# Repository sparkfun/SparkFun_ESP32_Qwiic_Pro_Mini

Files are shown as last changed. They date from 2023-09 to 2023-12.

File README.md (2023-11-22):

SparkFun ESP32 Qwiic Pro Mini
========================================

SparkFun ESP32 Qwiic Pro Mini (https://www.sparkfun.com/products/23386)

[*SparkFun ESP32 Qwiic Pro Mini (23386)*](https://www.sparkfun.com/products/23386)

<Basic description of the part.>

Repository Contents
-------------------

* **/Hardware** - Eagle design files (.brd, .sch)
* **/Documents** - Files related to the ESP32 Qwiic Pro Mini
* **/Firmware** - Production panel files (.brd)

Documentation
--------------
* **[Hookup Guide](http://docs.sparkfun.com/SparkFun_ESP32_Qwiic_Pro_Mini)** - Basic hookup guide for the SparkFun ESP32 Qwiic Pro Mini.

License Information
-------------------

This product is _**open source**_! 

Please review the LICENSE.md file for license information. 

If you have any questions or concerns on licensing, please contact technical support on our [SparkFun forums](https://forum.sparkfun.com/viewforum.php?f=152).

Distributed as-is; no warranty is given.

- Your friends at SparkFun.

_<COLLABORATION CREDIT>_

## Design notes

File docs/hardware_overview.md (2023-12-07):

---
icon: material/cog
---

## ESP32 PICO Mini 

At the core of the SparkFun ESP32 Qwiic Pro Mini is the ESP32-PICO-MINI-02-N8R2 variant which includes 8MB Flash and 2MB PSRAM. There are two CPU cores that can be individually controlled, and the CPU clock frequency is adjustable from 80 MHz to 240 MHz. The chip also has a low-power coprocessor that can be used instead of the CPU to save power while performing tasks that do not require much computing power, such as monitoring of peripherals. For more information, refer to the [datasheet](assets/board_files/Espressif_Systems_04082021_ESP32_PICO_MINI_02_N8R2-2295871.pdf). 

<figure markdown>
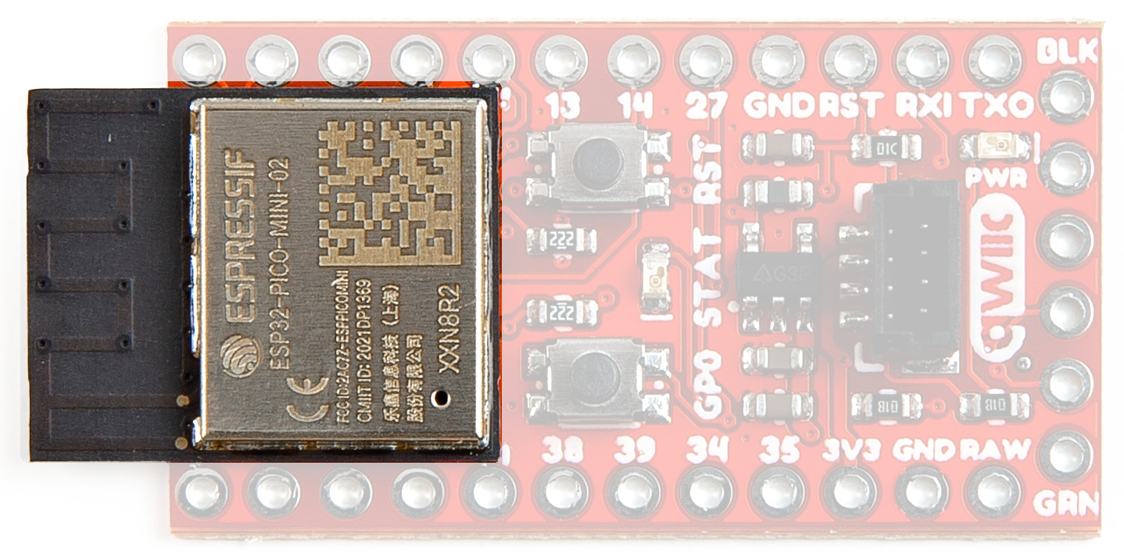
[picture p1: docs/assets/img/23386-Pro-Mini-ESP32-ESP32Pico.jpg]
ESP32 PICO Mini

<figcaption markdown>ESP32 PICO Mini</figcaption>
</figure>

## Power

Power is typically supplied via the VCC/GND pins using a [USB to Serial adapter](https://www.sparkfun.com/products/15096). Alternatively, external or portable power can be provided via the GND/RAW pins along the GPIO edge. Note: The AP2112K has a max input voltage of 6V.

The serial programming pins at the edge of the board are FTDI compatible and works best with our [CH340 USB to Serial breakout](https://www.sparkfun.com/products/15096). To utilize the GND/RAW pins along the GPIO edge, we recommend soldering the [JST Right-Angle Connector - Through-Hole 2-Pin](https://www.sparkfun.com/products/9749). 

<figure markdown>
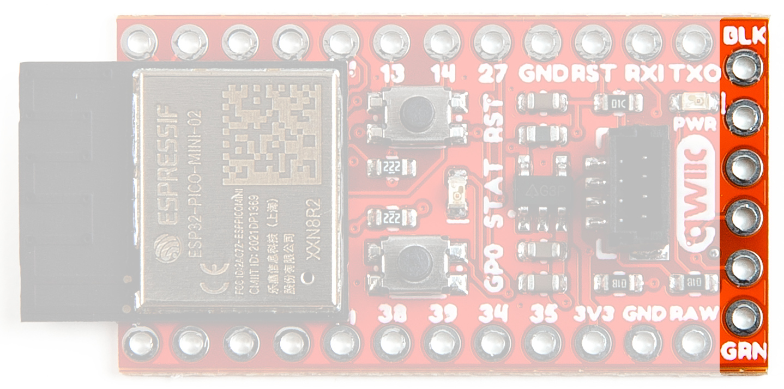
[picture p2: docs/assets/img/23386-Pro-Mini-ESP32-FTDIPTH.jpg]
FTDI PTHs

<figcaption markdown>Serial Programming Pins</figcaption>
</figure>

<figure markdown>
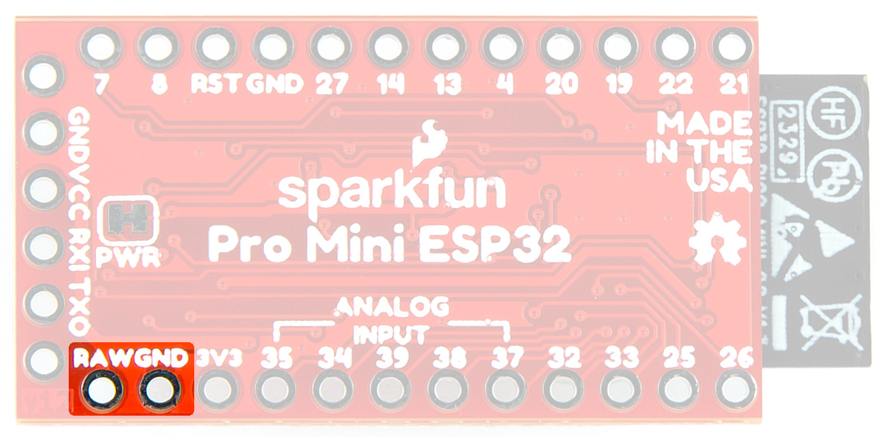
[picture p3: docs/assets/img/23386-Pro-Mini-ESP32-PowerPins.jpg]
Power PTHs

<figcaption markdown>Power Plated Through Holes</figcaption>
</figure>

## Voltage Regulator - AP2112K

The AP2112K Voltage Regulator ensures that the appropriate voltage is provided to the various components of the board. The AP2112K has a max input voltage of 6V.

<figure markdown>
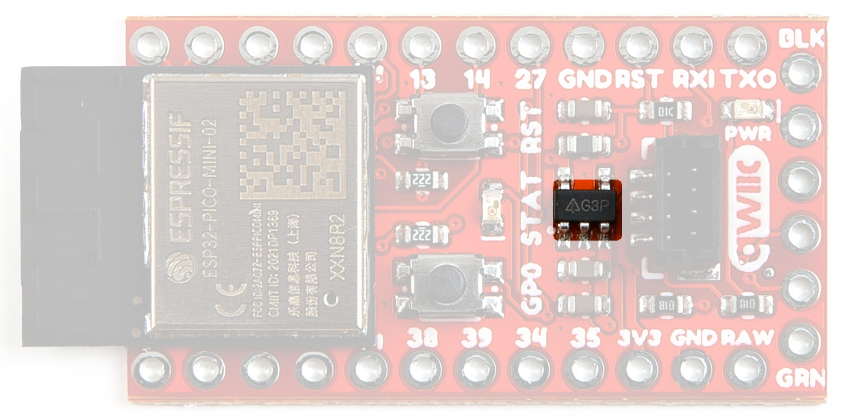
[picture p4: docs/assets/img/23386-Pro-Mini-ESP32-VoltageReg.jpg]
Voltage Regulator - AP2112K

<figcaption markdown>Voltage Regulator - AP2112K</figcaption>
</figure>

## Qwiic connector

The board includes a [Qwiic Connector](www.sparkfun.com/qwiic) for use with our vast array of Qwiic sensors. The I<sup>2</sup>C data and clock lines are tied to 2.2kΩ pull-up resistors.

Note that we've mounted the [Qwiic Connector](www.sparkfun.com/qwiic) vertically to prevent the occlusion of soldering and/or using the GPIO. 

<figure markdown>
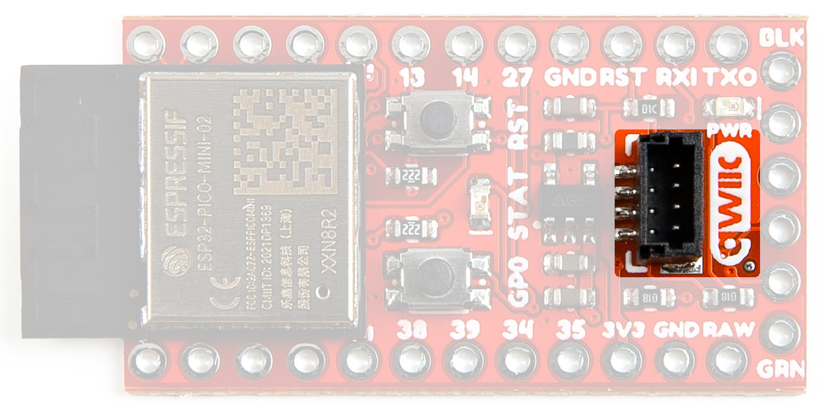
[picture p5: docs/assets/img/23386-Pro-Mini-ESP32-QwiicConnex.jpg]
Qwiic connector

<figcaption markdown>Qwiic connector</figcaption>
</figure>

## Buttons

There are two buttons on the board - Reset and Boot. The reset (RST) button allows users to reset the program running on the module without unplugging the board. The Boot Button allows the user to manually put the board into Bootloader Mode. To enter bootloader, hold the Boot button down when the ESP32 resets or powers on. These buttons are intentionally next to each other to make it a single finger rolling movement.

<figure markdown>
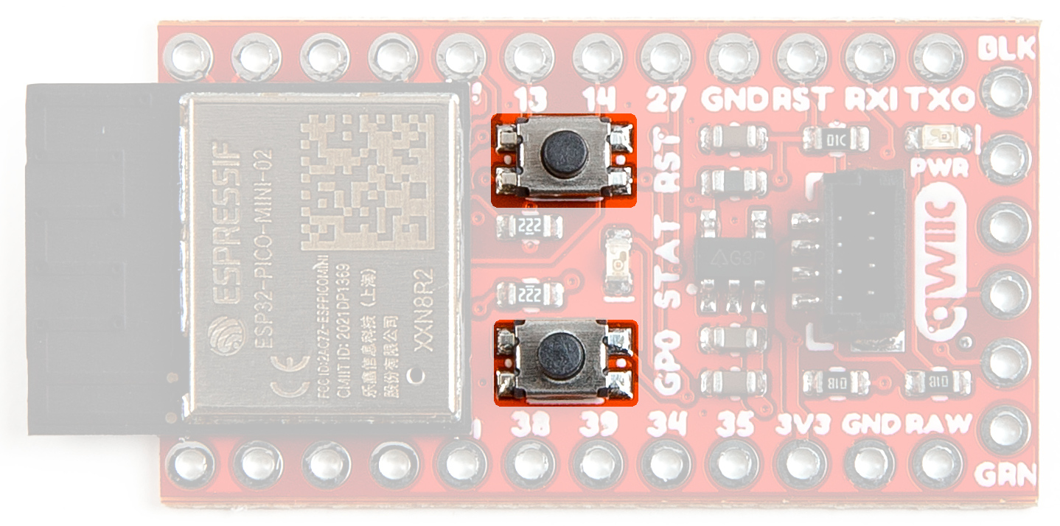
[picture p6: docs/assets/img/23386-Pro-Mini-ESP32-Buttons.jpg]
Buttons

<figcaption markdown>Buttons</figcaption>
</figure>

## LEDs

Two LEDs - Power(Red) and STAT(Blue) - show the user that power has been appropriately supplied to the board and the status of the data transfer. 

<figure markdown>
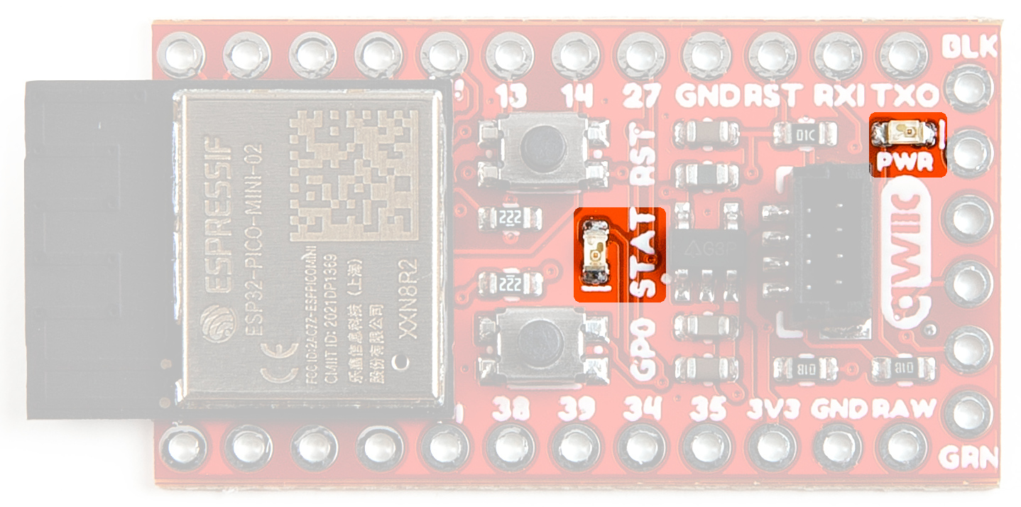
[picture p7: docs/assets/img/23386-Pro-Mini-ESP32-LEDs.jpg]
LEDs

<figcaption markdown>Power and Status LEDs</figcaption>
</figure>

## GPIO

The PTH pins are compatible with older Pro Minis. There are a few analog *input only* pins. They are labeled clearly.

<!--Use boot control pins with caution: 0, 2, 5, 12, 15
IO0: Avoid device connections. Can be used as a stat LED
IO2: Avoid external pullups - will cause bootloader fail
IO5: SDIO peripheral control. Has builtin pullup at POR
IO12: Avoid external pullups - will cause bootloader fail
IO15: Suppress output at POR. Has builtin pullup at POR
-->

<figure markdown>
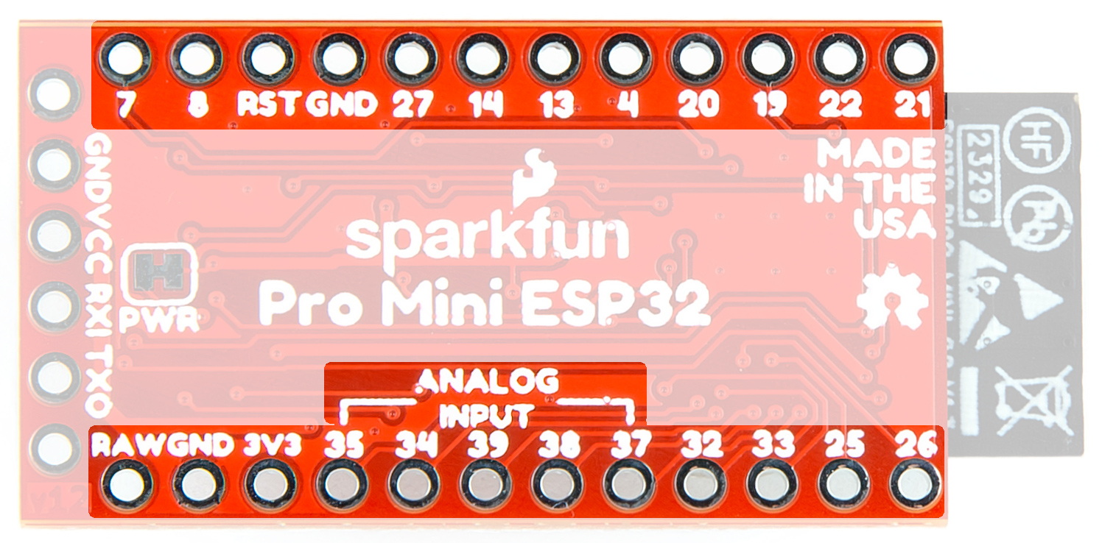
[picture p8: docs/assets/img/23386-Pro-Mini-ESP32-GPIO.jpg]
GPIO

<figcaption markdown>GPIO</figcaption>
</figure>

## Jumpers

??? note "Never modified a jumper before?"
	Check out our <a href="https://learn.sparkfun.com/tutorials/664">Jumper Pads and PCB Traces tutorial</a> for a quick introduction!
	<p align="center">
		<a href="https://learn.sparkfun.com/tutorials/664">
		Tutorial's thumbnail<br>
        How to Work with Jumper Pads and PCB Traces</a>
	</p>

### Power Jumper

If you have concerns about power consumption, need to run dark, or really just don't like LEDs, you can cut this jumper to disable the red PWR LED on the front of the board.

<figure markdown>
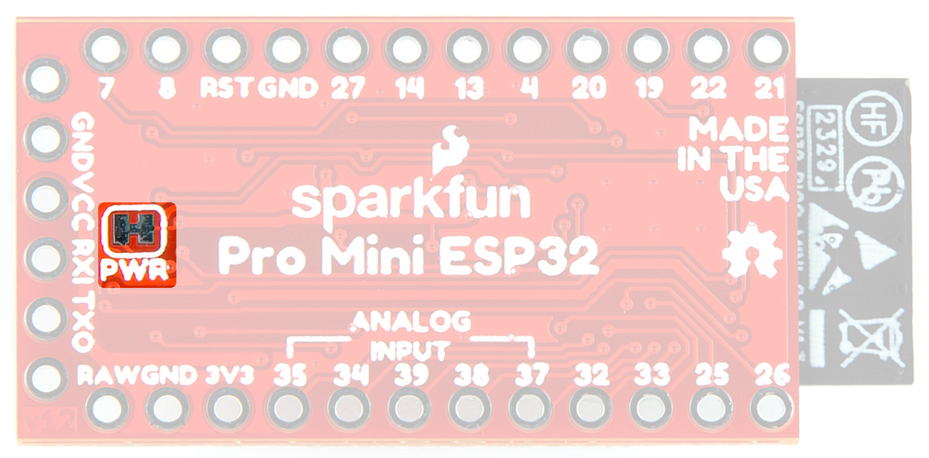
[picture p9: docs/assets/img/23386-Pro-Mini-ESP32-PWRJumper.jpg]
Power Jumper

<figcaption markdown>Power Jumper</figcaption>
</figure>

## Board Dimensions

The board dimensions are illustrated in the drawing below; the listed measurements are in inches.

<figure markdown>
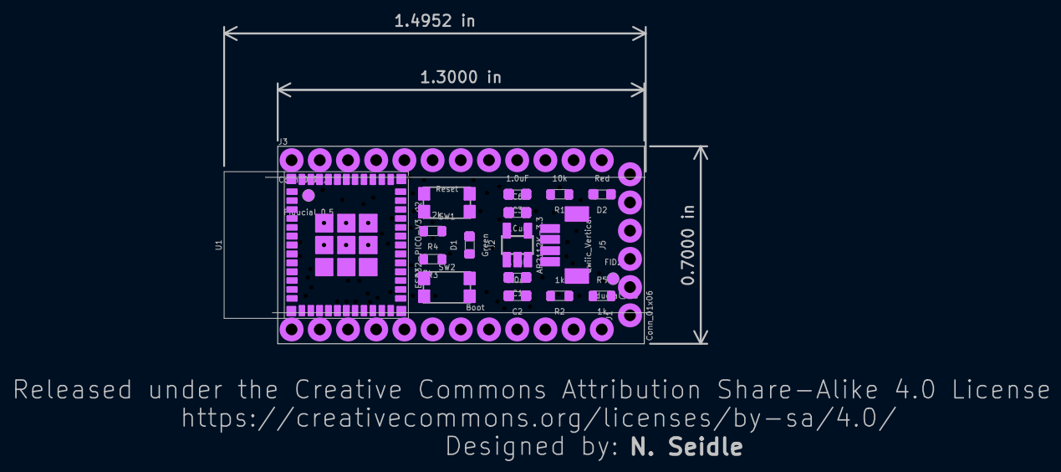
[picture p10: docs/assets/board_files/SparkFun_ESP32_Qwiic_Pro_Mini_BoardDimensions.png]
ESP32 Qwiic Pro Mini Board Dimensions

<figcaption markdown>ESP32 Qwiic Pro Mini Board Dimensions</figcaption>
</figure>

??? tip "Need more measurements?"
	For more information about the board's dimensions, users can download the [KiCad files](assets/board_files/SparkFun_ESP32_Qwiic_Pro_Mini-KiCadFiles.zip) for the board. These files can be opened in KiCad and additional measurements can be made with the dimensions tool.

	??? info ":octicons-download-16:{ .heart } KiCAD - Free Download!"
		KiCAD is a [CAD]("computer-aided design") program for electronics that is free to use for hobbyists and students. However, it does require an account registration to utilize the software.

		<center>
		[Download from<br>:autodesk-primary:{ .autodesk }](https://www.kicad.org/download/ "Go to downloads page"){ .md-button .md-button--primary width="250px" }
		</center>

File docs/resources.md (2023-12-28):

<!-- This section should include all the relevant documentation and product files (Eagle files, schematic, datasheet(s), landing pages, etc. and any relevant tutorials to go beyond the Hookup Guide.) -->

For more resources related to the SparkFun ESP32 Qwiic Pro Mini, check out the links listed here: 

* [Product Page](https://www.sparkfun.com/products/23386)
* [Schematic](assets/board_files/SparkFun_ESP32_Qwiic_Pro_Mini_SchematicV12.pdf) (PDF)
* [KiCAD Files](assets/board_files/SparkFun_ESP32_Qwiic_Pro_Mini-KiCAD_V12.zip) (ZIP)
* [Board Dimensions](assets/board_files/SparkFun_ESP32_Qwiic_Pro_Mini_BoardDimensions.png) (PDF)
* [Hardware GitHub Respository](https://github.com/sparkfun/SparkFun_ESP32_Qwiic_Pro_Mini)

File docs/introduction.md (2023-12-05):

---
icon: material/book-open-page-variant
---

<div class="grid cards desc" markdown>

-    <a href="https://www.sparkfun.com/products/23386">
    **SparkFun ESP32 Qwiic Pro Mini**<br>
    **SKU:** DEV-23386

    ---

    <figure markdown>
    Product Thumbnail
    </figure></a>
    
-    The SparkFun ESP32 Qwiic Pro Mini houses the powerful ESP32-PICO-MINI-02-N8R2 variant from Espressif on our mini footprint. With two individually controllable CPU cores, adjustable CPU clock frequency, 8MB Flash,  2MB PSRAM, a co-processor that can be used in situations that require minimal computing power, as well as a rich set of peripherals such as capabilities for SD card interface, capacitive touch sensors, ADC, DAC, Two-Wire Automotive Interface, to Ethernet, high-speed SPI, UART, I²S, and I²C. 

    <center>
    [Purchase from SparkFun :fontawesome-solid-cart-plus:{ .heart }](https://www.sparkfun.com/products/23386){ .md-button .md-button--primary }
    </center>

</div>

## Required Materials

To follow along with this tutorial, you will need the following materials. You may not need everything though depending on what you have. Add it to your cart, read through the guide, and adjust the cart as necessary.

<table style="border-style:none">
    <tr>
        <td>
            <a href="https://www.sparkfun.com/products/23386">
                <center>SparkFun ESP32 Qwiic Pro Mini</center>
                <h3 class="title">SparkFun ESP32 Qwiic Pro Mini</h3>
            </a>
            DEV-23386
        </td>
        <td>
            <a href=" https://www.sparkfun.com/products/15096">
                <center>SparkFun Serial Basic Breakout - CH340C and USB-C</center>
                <h3 class="title">SparkFun Serial Basic Breakout - CH340C and USB-C</h3>
            </a>
            DEV-15096
        </td>
        <td>
            <a href="https://www.sparkfun.com/products/15425">
                <center>Reversible USB A to C Cable - 0.8m
                </center>
                <h3 class="title">Reversible USB A to C Cable - 0.8m</h3>
            </a>
            CAB-15425
        </td>
    </tr>
</table>

## Suggested Reading

As a more professionally oriented product, we will skip over the more fundamental tutorials (i.e. [**Ohm's Law**](https://learn.sparkfun.com/tutorials/voltage-current-resistance-and-ohms-law) and [**What is Electricity?**](https://learn.sparkfun.com/tutorials/what-is-electricity)). However, below are a few tutorials that may help users familiarize themselves with various aspects of the board.

<div class="grid cards hide col-4" markdown align="center">

-   <a href="https://learn.sparkfun.com/tutorials/how-to-solder-through-hole-soldering">
    <figure markdown>
    How to Solder: Through-Hole Soldering
    </figure>
    </a>
    <a href="https://learn.sparkfun.com/tutorials/how-to-solder-through-hole-soldering">**How to Solder: Through-Hole Soldering**
    </a>

-   <a href="https://learn.sparkfun.com/tutorials/sparkfun-serial-basic-ch340c-hookup-guide">
    <figure markdown>
    SparkFun Serial Basic CH340C Hookup Guide
    </figure>
    </a>
    <a href="https://learn.sparkfun.com/tutorials/sparkfun-serial-basic-ch340c-hookup-guide">**SparkFun Serial Basic CH340C Hookup Guide**
    </a>    

-   <a href="https://learn.sparkfun.com/tutorials/82">
    <figure markdown>
    I2C
    </figure>
    </a>
    <a href="https://learn.sparkfun.com/tutorials/82">**I2C**
    </a>

-   <a href="https://learn.sparkfun.com/tutorials/analog-vs-digital">
    <figure markdown>
    Analog vs. Digital
    </figure>
    </a>
    <a href="https://learn.sparkfun.com/tutorials/analog-vs-digital">**Analog vs. Digital**
    </a>

-   <a href="https://learn.sparkfun.com/tutorials/serial-peripheral-interface-spi">
    <figure markdown>
    SPI
    </figure>
    </a>
    <a href="https://learn.sparkfun.com/tutorials/serial-peripheral-interface-spi">**SPI**
    </a>
</div>

<center>
<div align="center">
    <div style="top:5px;left:5px;background-color:Gray;position:relative">
        <div style="top:-5px;left:-5px;background-color:#ffffff;position:relative;border:1px solid black;">
            <a href="https://www.sparkfun.com/qwiic">Qwiic Connect System</a>
        </div>
    </div>
</div>
</center>

The SparkFun ESP32 Qwiic Pro Mini takes advantage of the [Qwiic connect system](https://www.sparkfun.com/qwiic). We recommend familiarizing yourself with the **Logic Levels** and **I<sup>2</sup>C** tutorials.  Click on the banner above to learn more about [Qwiic products](https://www.sparkfun.com/qwiic).

<center>
    <iframe width="600" height="327" src="https://www.youtube.com/embed/x0RDEHqFIF8" title="SparkFun's Qwiic Connect System" frameborder="0" allow="accelerometer; autoplay; clipboard-write; encrypted-media; gyroscope; picture-in-picture" allowfullscreen></iframe>
</center>

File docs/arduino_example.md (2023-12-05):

---
icon: simple/arduino
---

Now that we've installed the espressif boards package in Arduino, it's time to upload our first sketch to make sure everything is working properly.

### Example - Blink 

This basic example makes sure the board package installed correctly and the board accepts programming properly to blink the green STAT LED on the board every second. Open the example in Arduino by navigating to File > Examples > Basics > 01-Blink.

You will need to modify LED_BUILTIN to pin 0 like so: 

<figure markdown>
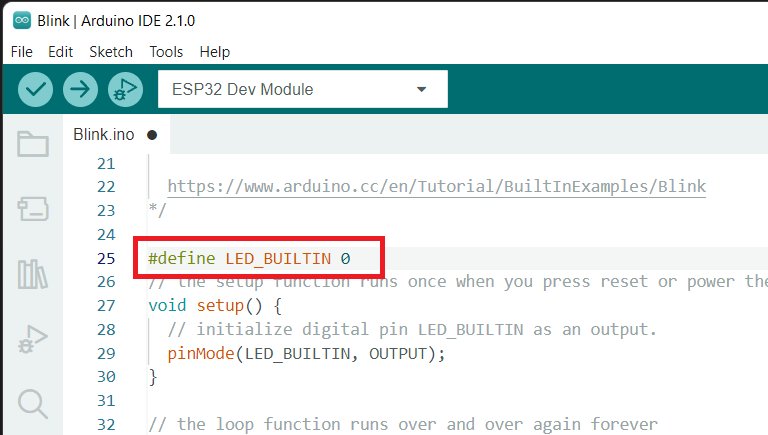
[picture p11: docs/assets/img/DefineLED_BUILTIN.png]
LED Builtin is Defined

<figcaption markdown>Code changes for LED_BUILTIN</figcaption>
</figure>

Make sure you have the board (ESP32 Dev Board) and select your applicable COM port: 

<figure markdown>
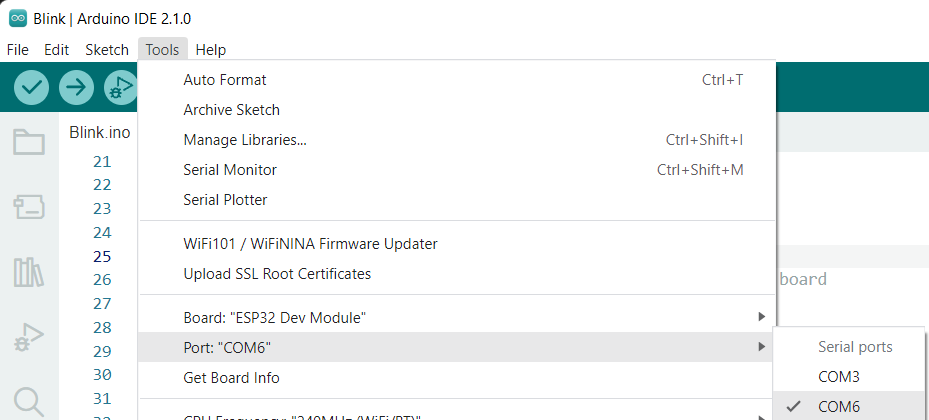
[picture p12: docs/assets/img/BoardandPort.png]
Board and Port selected

<figcaption markdown>Board and Port selected</figcaption>
</figure>

### Uploading Code

!!! attention 
    While most ESP32 boards include an auto-reset and auto-bootload circuitry, these have been removed from the ESP32 Pro Mini to save space. This means you will need to manually enter and exit the bootloader mode every time new code is to be loaded.

Before uploading, you'll need to put the board into the <a href="https://docs.espressif.com/projects/esptool/en/latest/esp32/advanced-topics/boot-mode-selection.html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">serial bootloader</a> with the <kbd>BOOT</kbd> button. Holding down the <kbd>BOOT</kbd> button, while connecting the board to a computer through its USB-C connector or resetting the board will cause the MCU to enter the <a href="https://docs.espressif.com/projects/esptool/en/latest/esp32/advanced-topics/boot-mode-selection.html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">Firmware Download mode</a> and its serial bootloader. The board will remain in this mode until it is power cycled by either pressing the <kbd>RST</kbd> button or the board is unplugged/plugged in.

1. Hold the <kbd>BOOT</kbd> button down.
2. Reset the MCU. This can be accomplished by:
    * Plugging the board into a USB to Serial board.
    * Or, press and releasing the RST button while holding BOOT.
3. Release the <kbd>BOOT</kbd> button.
4. After programming is completed, reboot the MCU.
    * Press the <kbd>RST</kbd> button.
    * Or, power cycle the board. 

Once the board is in the serial bootloader, you can upload code through the Arduino interface. Once your code is uploaded, you will need to hit the <kbd>RST</kbd> button to get your sketch running. 

<figure markdown>
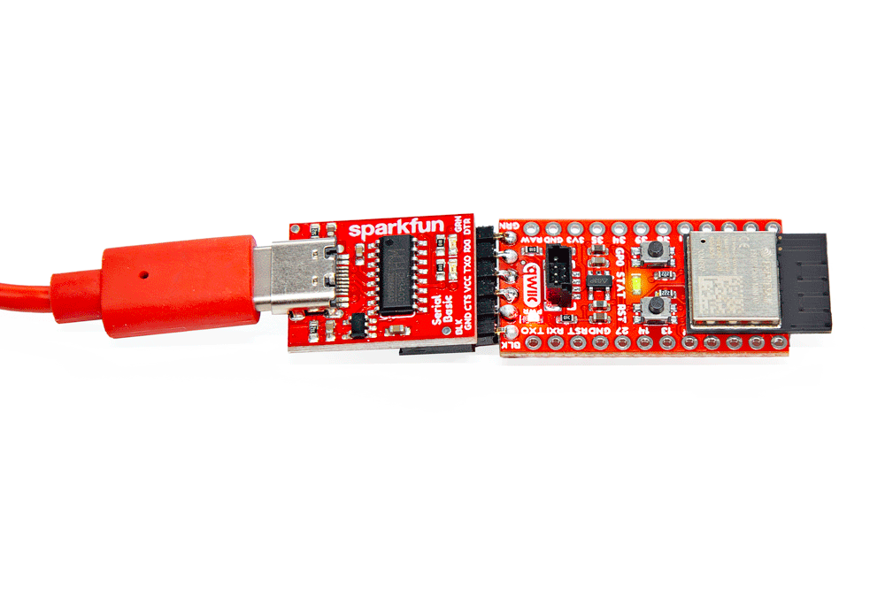
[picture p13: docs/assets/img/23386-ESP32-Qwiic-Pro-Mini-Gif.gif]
Blink Example

<figcaption markdown>Blink Example</figcaption>
</figure>

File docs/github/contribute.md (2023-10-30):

# Contribute: Make an Augmentation!
Spot an improvement opportunity? Feel free to contribute to our open-source design and documentation. 

## :material-file-document-multiple:&nbsp;Improve our Documentation
All of this documentation can be modified by you! Please help us make it better.

* These pages are contained in the [`docs` folder](https://github.com/sparkfun/SparkFun_ESP32_Qwiic_Pro_Mini/tree/main/docs) of the [SparkFun ESP32 Qwiic Pro Mini repository](https://github.com/sparkfun/SparkFun_ESP32_Qwiic_Pro_Mini).

<!-- ### :material-source-pull:&nbsp;Submit a Correction -->
### Submit a Correction

1. With a GitHub account, [fork this repository](https://github.com/sparkfun/SparkFun_ESP32_Qwiic_Pro_Mini/fork).
2. Add your corrections or improvements to the markdown file.
3. File a pull request with your changes, and enjoy making the ~~words~~ ~~worlds~~ world a better place.
	* Once received, the documentation specialist will automatically be notified.
	* We will review your suggested improvements to make sure they are correct and fit within our documentation standards.

## :material-cog:&nbsp;Improve our Hardware Design
All of our designs are open-source! Please help us make it better.

* Our board design files are contained in the [`Hardware` folder](https://github.com/sparkfun/SparkFun_ESP32_Qwiic_Pro_Mini/tree/main/Hardware) of the [SparkFun ESP32 Qwiic Pro Mini repository](https://github.com/sparkfun/SparkFun_ESP32_Qwiic_Pro_Mini).

<!-- ### :material-source-pull:&nbsp;Submit a Design Enhancement -->
### Submit a Design Enhancement

1. With a GitHub account, [fork this repository](https://github.com/sparkfun/SparkFun_ESP32_Qwiic_Pro_Mini/fork).
2. Add your design augmentation(s)
3. File a pull request with your changes, and enjoy making the ~~words~~ ~~worlds~~ world a better place.
	1. Once received, the engineer in charge of the original design will automatically be notified.
	2. We will review your suggested improvement(s) to verify that they are within our board design standards and meet our product design requirements.
	3. If approved, we will flag these changes for our next board revision. Congrats! 🍻

		!!! info
			Even if your suggestion is accepted, these changes may not be immediately available for purchase. We may have to cycle through our current product inventory first.

## Contributors&nbsp;:clap:
Let's provide some recognition to the contributors for this project!

GitHub Contributors Image
<br>


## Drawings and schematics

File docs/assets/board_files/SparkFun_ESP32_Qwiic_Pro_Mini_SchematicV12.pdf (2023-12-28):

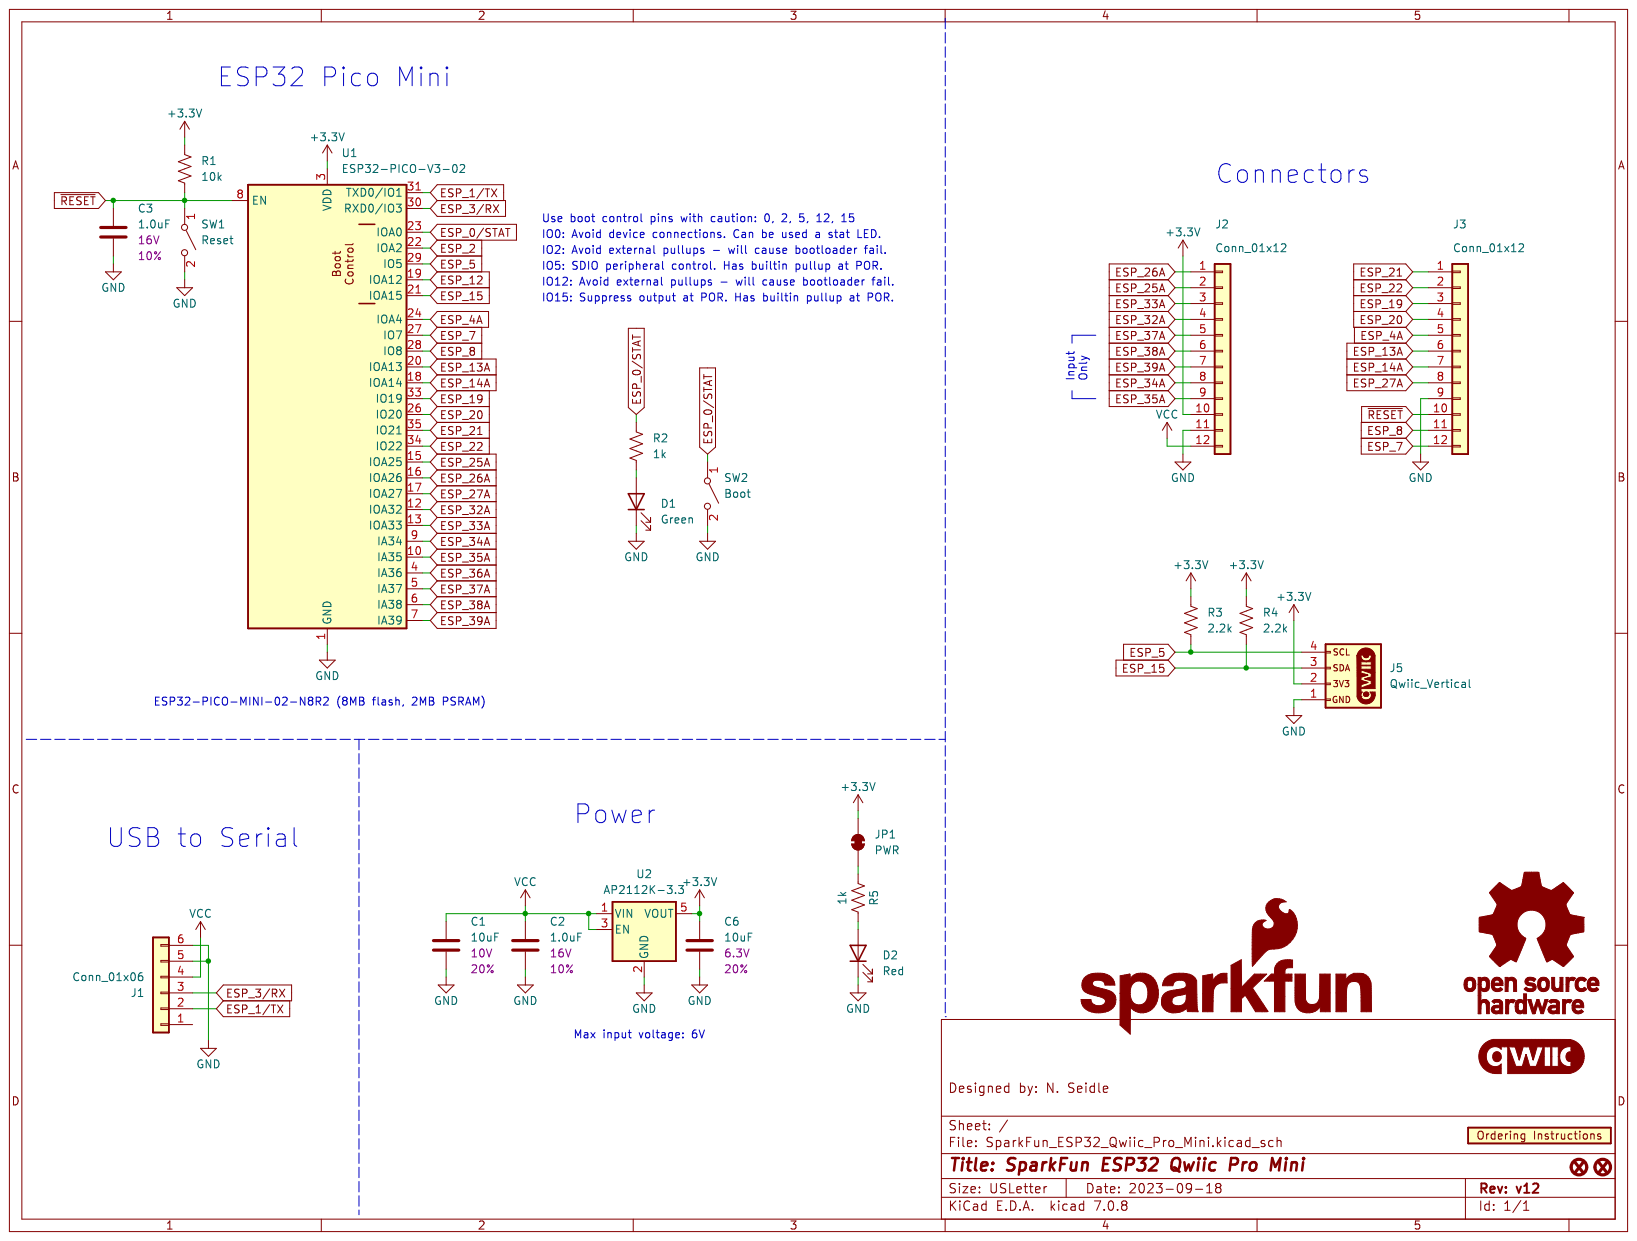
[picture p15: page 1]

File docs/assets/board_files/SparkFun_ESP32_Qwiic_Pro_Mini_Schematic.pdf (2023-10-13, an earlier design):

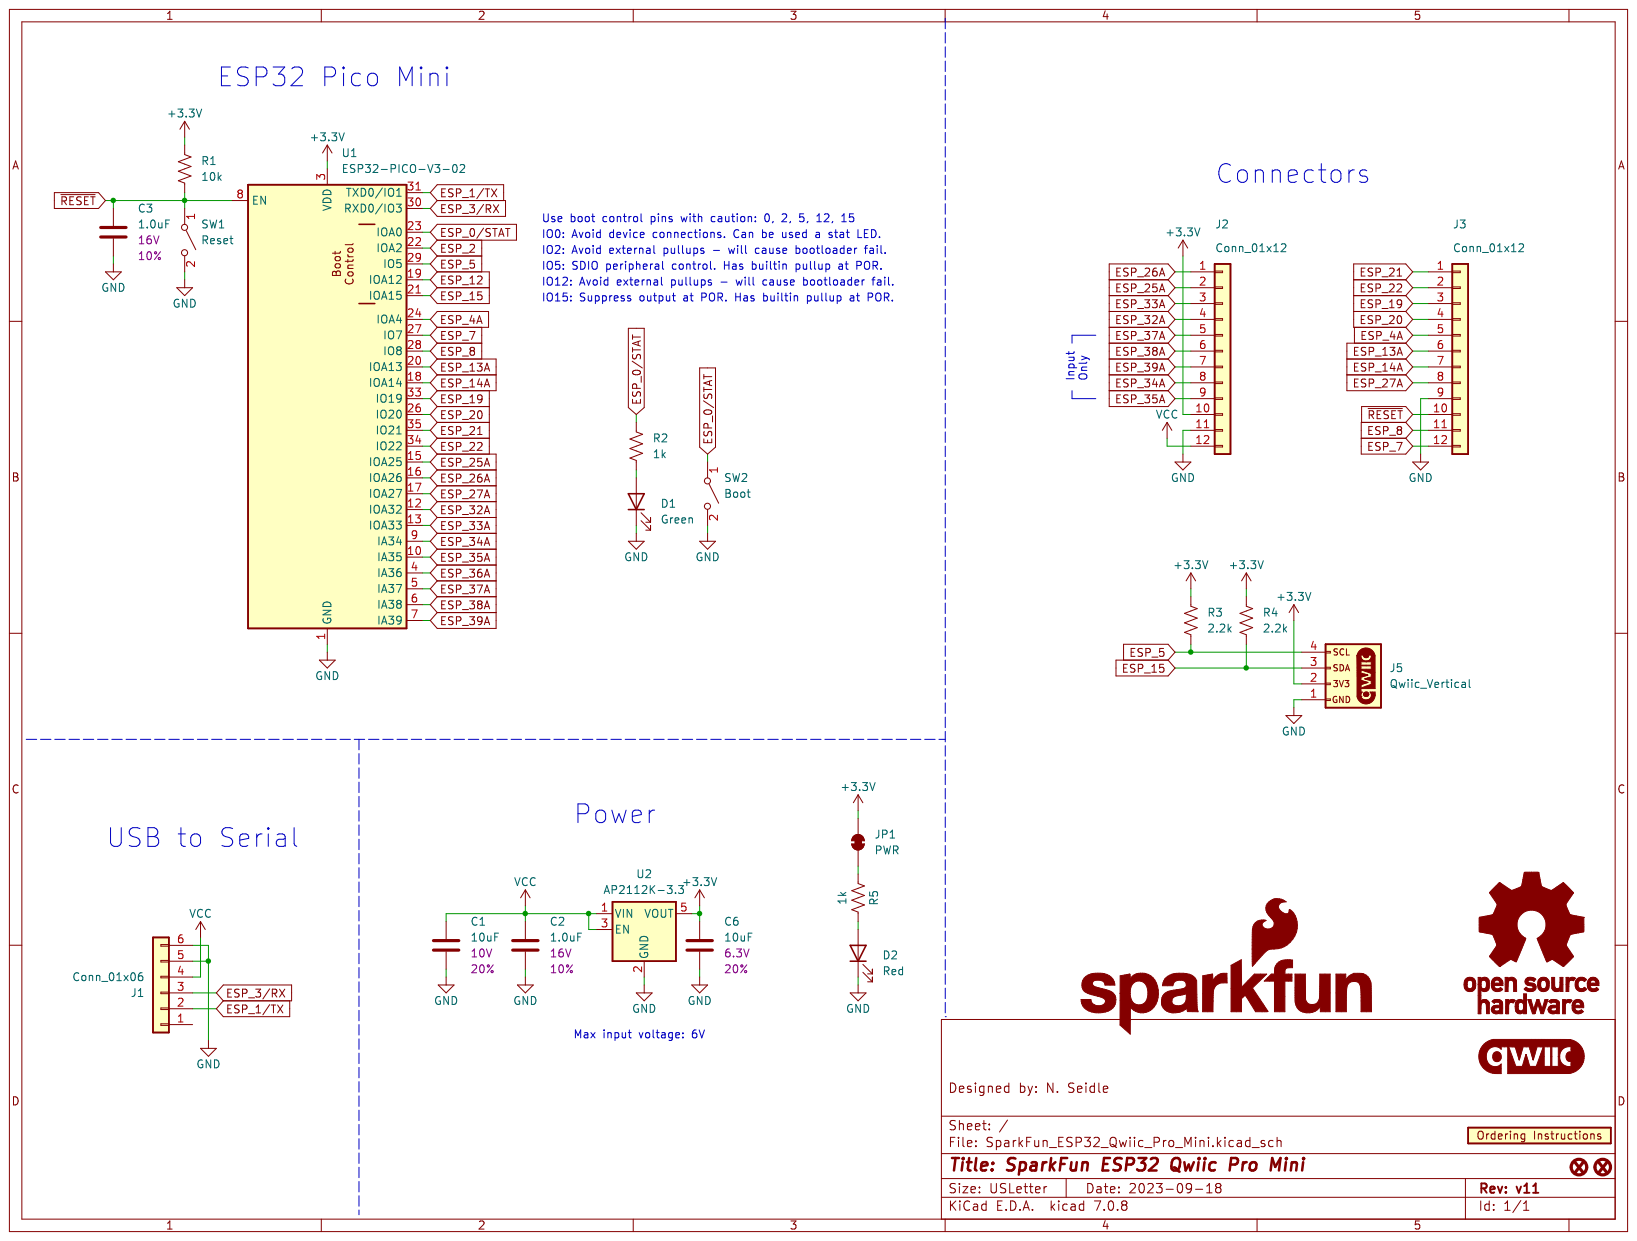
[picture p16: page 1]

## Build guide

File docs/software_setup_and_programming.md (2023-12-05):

---
icon: simple/arduino
---

With the ESP32 Qwiic Pro Mini Board connected to our computer, it's time to set up the boards package in Arduino.

!!! attention
	If this is your first time using Arduino, please read through our tutorial on [installing the Arduino IDE](https://learn.sparkfun.com/tutorials/installing-arduino-ide). If you have not installed an Arduino library before, we recommend you check out our [installation guide](https://learn.sparkfun.com/tutorials/installing-an-arduino-library).

## Installing espressif Arduino Boards

Install the espressif ESP32 Arduino Boards package by opening the Boards Manager tab on the left side of the IDE, then search for "espressif ESP32" and install the latest version of the ESP32 boards package as the screenshot below shows. This assumes the use of Arduino 2.x. Legacy users (Arduino 1.8x and previous) can find the Boards Manager tool in File/Tools/Boards Manager.

<figure markdown>
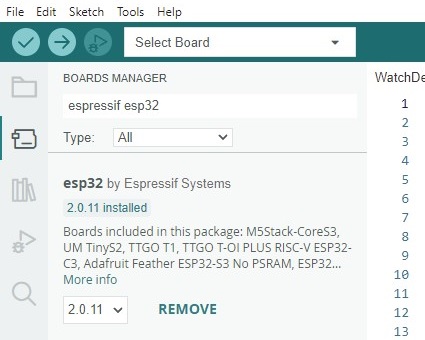
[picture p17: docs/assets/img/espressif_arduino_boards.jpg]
ESP32 Boards manager install.

</figure>

<p><b>Note:</b> For more instructions, users can follow this tutorial on <a href="https://docs.arduino.cc/learn/starting-guide/cores">Installing Additional Cores</a> provided by Arduino. Users will also need the <code>.json</code> file for the Espressif Arduino core:</p>
    
``` 
    https://raw.githubusercontent.com/espressif/arduino-esp32/gh-pages/package_esp32_index.json
```

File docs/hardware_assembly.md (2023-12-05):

---
icon: fontawesome/solid/screwdriver-wrench
---

To program this board, and to use any of the I/O, you'll need to solder _something_ to the board. In the least, we recommend soldering [right-angle male headers](https://www.sparkfun.com/products/553) or [straight male headers](https://www.sparkfun.com/products/116) onto the six-pin serial header. Either of these will interface easily with the [SparkFun Serial Basic Breakout - CH340C and USB-C](https://www.sparkfun.com/products/15096).

??? note "New to soldering?"
	If you have never soldered before or need a quick refresher, check out our [How to Solder: Through-Hole Soldering](https://learn.sparkfun.com/tutorials/how-to-solder-through-hole-soldering) guide.

	<div class="grid cards col-4" markdown  align="center">

	-   <a href="https://learn.sparkfun.com/tutorials/5">
		<figure markdown>
		Tutorial thumbnail
		</figure>

		---
		
		**How to Solder: Through-Hole Soldering**</a>

	</div>

<figure markdown>
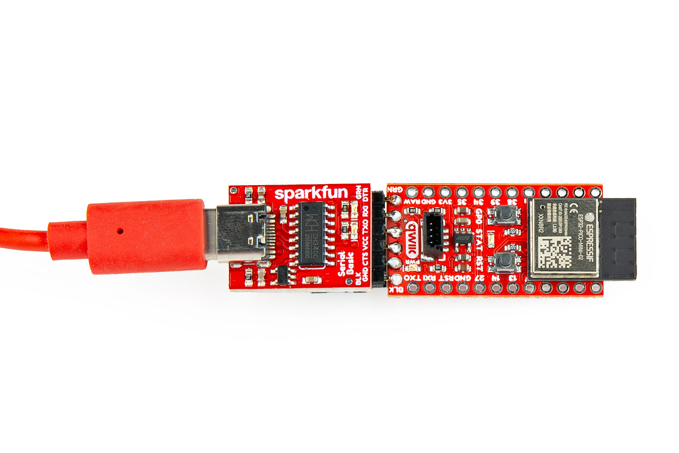
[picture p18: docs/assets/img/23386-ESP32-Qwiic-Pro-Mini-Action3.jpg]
ESP32 Connected to Programming

<figcaption markdown>ESP32 Connected to Programming</figcaption>
</figure>

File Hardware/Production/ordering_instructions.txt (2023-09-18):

Ordering Instructions:
Panel dimensions: 172.68 x 141.16 mm.
Material: TG135-140
Solder Mask: Red
Silkscreen: White
Layers: 2
Finish: HASL Lead Free
Thickness: 0.8mm
Copper Weight: 1oz
Minimum track width: 0.15mm (6.00mil)
Minimum via drill: 0.30mm (11.81mil)

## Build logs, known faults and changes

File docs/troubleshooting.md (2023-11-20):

---
icon: fontawesome/solid/question
---

!!! note
    <span class="glyphicon glyphicon-question-sign" aria-hidden="true"></span>
        <strong> Not working as expected and need help? </strong> <br /><br />

    If you need technical assistance and more information on a product that is not working as you expected, we recommend heading on over to the <a href="https://www.sparkfun.com/technical_assistance">SparkFun Technical Assistance</a> page for some initial troubleshooting. <br /><br />

    <div style="text-align: center"><a href="https://www.sparkfun.com/technical_assistance" target="sfe_technical_assistance" class="md-button">SparkFun Technical Assistance Page</a></div>

    If you don't find what you need there, the <a href="https://forum.sparkfun.com/index.php">SparkFun Forums</a> are a great place to find and ask for help. If this is your first visit, you'll need to <a href="https://forum.sparkfun.com/ucp.php?mode=register">create a Forum Account</a> to search product forums and post questions.<br /><br />

    <div style="text-align: center"><a href="https://forum.sparkfun.com/ucp.php?mode=register" class="md-button">Create New Forum Account</a>&nbsp;&nbsp;&nbsp;<a href="https://forum.sparkfun.com/index.php" class="md-button md-button--primary">Log Into SparkFun Forums</a></div>

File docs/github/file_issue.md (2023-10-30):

# Did we make a mistake?

Spot something wrong? Please let us know. 

<!-- Technical Assistance Box -->
!!! warning "Need Help?"
    If you need technical assistance or more information on a product that is not working as you expected, we recommend heading on over to the [SparkFun Technical Assistance](https://www.sparkfun.com/technical_assistanc) page for some initial troubleshooting. This **Submit Issues** page is not where users should seek assistance.

    <center>
    [SparkFun Technical Assistance Page](https://www.sparkfun.com/technical_assistance){ .md-button .md-button--primary }
    </center>
    
    If you can't find what you need there, the [SparkFun Forums](https://forum.sparkfun.com/index.php) is a great place to search the product forums and ask questions.
    
    !!! info "Account Registration Required"
        For your first visit to our forum, you'll need to create a [Forum Account](https://forum.sparkfun.com/ucp.php?mode=register) to post questions.

## Discrepancies in the Documentation

All of our documentation can be modified by you! Please help us make it better.

* The documentation files for these pages are contained in the [`docs` folder](https://github.com/sparkfun/SparkFun_ESP32_Qwiic_Pro_Mini/tree/main/docs) of the [SparkFun ESP32 Qwiic Pro Mini repository](https://github.com/sparkfun/SparkFun_ESP32_Qwiic_Pro_Mini).

### 🔍 Spot something wrong?

If a section of the documentation is incorrect, please [open an issue](https://github.com/sparkfun/SparkFun_ESP32_Qwiic_Pro_Mini/issues) and let us know.

### Do you have a suggested correction?

1. With a GitHub account, [fork this repository](https://github.com/sparkfun/SparkFun_ESP32_Qwiic_Pro_Mini/fork).
2. Add your correction(s) or improvement(s) to the markdown file(s)
3. File a pull request with your changes, and enjoy making the ~~words~~ ~~worlds~~ world a better place.
	* Once received, the documentation specialist will automatically be notified.
	* We will review your suggested improvement(s) to make sure they are correct and fit within our documentation standards.

## Problems in the Hardware Design

All of our designs are open-source! Please help us make it better.

* Our board design files are contained in the [`Hardware` folder](https://github.com/sparkfun/SparkFun_ESP32_Qwiic_Pro_Mini/tree/main/Hardware) of the [SparkFun ESP32 Qwiic Pro Mini repository](https://github.com/sparkfun/SparkFun_ESP32_Qwiic_Pro_Mini).

### Does something not make sense? 🤔

If part of the design is confusing, please [open an issue](https://github.com/sparkfun/SparkFun_ESP32_Qwiic_Pro_Mini/issues) and let us know.

### Did we forget to include an important function of the board? 🤦

If part of the board's functionality is missing, please [open an issue](https://github.com/sparkfun/SparkFun_ESP32_Qwiic_Pro_Mini/issues) and file a feature request.

!!! tip "Design Considerations"
	Please keep in mind that we may intentionally exclude certain functions of the board to meet our product design requirements.
	
	* *For example, our Qwiic Micro boards are intended to fit on a small board layout and only use I<sup>2</sup>C communication; therefore, we may not have the SPI and interrupt pins available for users.*

### Do you wish to contribute directly to improving the board design?

1. With a GitHub account, [fork this repository](https://github.com/sparkfun/SparkFun_ESP32_Qwiic_Pro_Mini/fork).
2. Add your design augmentation(s)
3. File a pull request with your changes, and enjoy making the ~~words~~ ~~worlds~~ world a better place.
	1. Once received, the engineer in charge of the original design will automatically be notified.
	2. We will review your suggested improvement(s) to verify that they are within our board design standards and meet our product design requirements.
	3. If approved, we will flag these changes for our next board revision. Congrats! 🍻

		!!! info
			Even if your suggestion is accepted, these changes may not be immediately available for purchase. We may have to cycle through our current product inventory first.

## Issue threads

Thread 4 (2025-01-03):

Pro Mini I2C is still non-obvious

zyphlar, 2025-01-03:
#3 was marked as completed but it's not complete. Nowhere in the instructions is it obvious that we should install/use/reference the Pro Mini examples in order to figure out how to use it for its primarily-advertised function, easily using Qwiic.

I highly recommend adding a "using Qwiic/I2C" example to the Qwiic Pro Mini [getting started guide](https://docs.sparkfun.com/SparkFun_ESP32_Qwiic_Pro_Mini/introduction/), not just Blink. Or at the very least a final getting started step that directs users to the proper examples folder. Or under the Hardware overview, enumerating what the various pin numbers are and highlighting the fact that Qwiic.begin() won't work out of the box.

I "knew" all this but again wasted 2+ hours wondering why things were failing on this easy Qwiic-branded product when it worked fine on my Teensy... because I assumed Qwiic would "just work" whereas Teensy comes with a very obvious "this is SDA/SCL" pinout graphic. I didn't go over to Qwiic Pro Mini examples that I've never used (partially because I'm using the ESP32 Dev Module board in Arduino, Arduino IDE doesn't know what a Qwiic Pro Mini is), I started remembering the limitations of the docs I ran into previously and navigated back to this old issue.

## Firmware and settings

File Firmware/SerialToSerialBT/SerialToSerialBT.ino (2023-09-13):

//This example code is in the Public Domain (or CC0 licensed, at your option.)
//By Evandro Copercini - 2018
//
//This example creates a bridge between Serial and Classical Bluetooth (SPP)
//and also demonstrate that SerialBT have the same functionalities of a normal Serial

#include "BluetoothSerial.h"

BluetoothSerial SerialBT;

#include "esp_bt_device.h"

char macAddress[strlen("E8:9F:6D:22:37:72")] = {0};

void setup() {
  Serial.begin(115200);
  delay(250); //Wait for serial port to open

  SerialBT.begin("SparkFun"); //Bluetooth device name

  Serial.println("The device has started. Now you can pair it with Bluetooth!");

  const uint8_t* mAdr = esp_bt_dev_get_address();

  for (int i = 0 ; i < 6 ; i++)
  {
    char str[3];
    sprintf(str, "%02X", (int)mAdr[i]);
    strcat(macAddress, str);

    if (i < 5)
      strcat(macAddress, ":");
  }

  Serial.printf("Bluetooth MAC: %s\r\n", macAddress);
}

void loop()
{
  if (Serial.available()) {
    SerialBT.write(Serial.read());
  }
  if (SerialBT.available()) {
    Serial.write(SerialBT.read());
  }

  char myString[500];
  sprintf(myString, "Hello %s how are you today? Is it going well? How is the weather? Let's talk again soon!", macAddress);
  SerialBT.println(myString);
  delay(100);
}

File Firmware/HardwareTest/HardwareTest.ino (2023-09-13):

/*
*/

uint8_t pin_button = 0;
uint8_t pin_statusLED = 0;
uint8_t pin_tx1 = 7;
uint8_t pin_rx1 = 8;

unsigned long lastChange = 0;

void setup()
{
  Serial.begin(115200); // Start serial for any initial debug messages

  pinMode(pin_button, INPUT_PULLUP);

  pinMode(pin_statusLED, OUTPUT);
  digitalWrite(pin_statusLED, LOW);

  pinMode(26, OUTPUT);
  digitalWrite(26, LOW);

  pinMode(25, OUTPUT);
  digitalWrite(25, HIGH);

  pinMode(33, OUTPUT);
  digitalWrite(33, HIGH);

  pinMode(32, OUTPUT);
  digitalWrite(32, LOW);

  pinMode(37, OUTPUT);
  digitalWrite(37, HIGH);

  pinMode(27, OUTPUT);
  digitalWrite(27, LOW);

  pinMode(14, OUTPUT);
  digitalWrite(14, HIGH);

  pinMode(13, OUTPUT);
  digitalWrite(13, LOW);

  pinMode(4, OUTPUT);
  digitalWrite(4, HIGH);

  pinMode(20, OUTPUT);
  digitalWrite(20, LOW);

  pinMode(19, OUTPUT);
  digitalWrite(19, HIGH);

  pinMode(22, OUTPUT);
  digitalWrite(22, LOW);

  pinMode(21, OUTPUT);
  digitalWrite(21, HIGH);

  pinMode(pin_tx1, OUTPUT);
  digitalWrite(pin_tx1, LOW);

  pinMode(pin_rx1, OUTPUT);
  digitalWrite(pin_rx1, HIGH);
}

void loop()
{
  Serial.println("Running");

  if (millis() - lastChange > 3000)
  {
    lastChange = millis();
    digitalWrite(pin_statusLED, !digitalRead(pin_statusLED));

    digitalWrite(26, !digitalRead(26));
    digitalWrite(25, !digitalRead(25));

    digitalWrite(33, !digitalRead(33));
    digitalWrite(32, !digitalRead(32));
    digitalWrite(37, !digitalRead(37));
    digitalWrite(27, !digitalRead(27));
    digitalWrite(14, !digitalRead(14));
    digitalWrite(13, !digitalRead(13));
    digitalWrite(4, !digitalRead(4));
    digitalWrite(20, !digitalRead(20));
    digitalWrite(19, !digitalRead(19));
    digitalWrite(22, !digitalRead(22));
    digitalWrite(21, !digitalRead(21));

    digitalWrite(pin_rx1, !digitalRead(pin_rx1));
    digitalWrite(pin_tx1, !digitalRead(pin_tx1));
  }

  if (digitalRead(pin_button) == LOW)
    Serial.println("Button pressed!");

  delay(100);

}

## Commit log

2023-08-30 Update status LED to green.
    [SparkFun_Pro_Mini-ESP32.kicad_pcb, SparkFun_Pro_Mini-ESP32.kicad_sch]
2023-09-13 Add PWR LED. Change to vertical Qwiic.
    [SparkFun_ESP32_Qwiic_Pro_Mini.kicad_pcb, SparkFun_ESP32_Qwiic_Pro_Mini.kicad_sch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]
2023-09-13 Remove stray label
    [SparkFun_ESP32_Qwiic_Pro_Mini.kicad_pcb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]
2023-09-18 Post review changes.
    [SparkFun_ESP32_Qwiic_Pro_Mini.kicad_pcb, SparkFun_ESP32_Qwiic_Pro_Mini.kicad_sch]
2023-09-18 Post design review fixes.
    [SparkFun_ESP32_Qwiic_Pro_Mini.kicad_pcb, SparkFun_ESP32_Qwiic_Pro_Mini.kicad_sch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]
2023-09-18 Add fiducials
    [SparkFun_ESP32_Qwiic_Pro_Mini.kicad_pcb, SparkFun_ESP32_Qwiic_Pro_Mini.kicad_sch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]
2023-10-05 Update SparkFun_ESP32_Qwiic_Pro_Mini.kicad_sch
    Verbiage change
    [SparkFun_ESP32_Qwiic_Pro_Mini.kicad_sch]
2023-10-20 Adding arduino example and updating photos
2023-10-23 Adding hardware assembly page and changes to introduction
2023-11-17 Minor changes to correct I2C and list GPIO
2023-12-05 Updates to hardware and assembly
2023-12-05 Adding copy button to JSON link
2023-12-08 Fix bad silk. Update to v12.
    [SparkFun_ESP32_Qwiic_Pro_Mini.kicad_pcb, SparkFun_ESP32_Qwiic_Pro_Mini.kicad_sch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]
2023-12-08 Updating schematic and zip files to v1.2
2023-12-08 Autosave did not save- updating sch
    [SparkFun_ESP32_Qwiic_Pro_Mini.kicad_sch]
2024-08-19 Update 3D models
    [SparkFun_ESP32_Qwiic_Pro_Mini.kicad_pcb, SparkFun_ESP32_Qwiic_Pro_Mini.kicad_sch]
